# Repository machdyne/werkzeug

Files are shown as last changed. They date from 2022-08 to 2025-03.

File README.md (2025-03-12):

# Werkzeug USB Multi-Tool

Werkzeug is a USB multi-tool that can be used as a universal programmer, USB-UART bridge, USB-SPI bridge, USB-I2C bridge, USB host bridge, USB-PMOD bridge, programmable GPIO bit-bang device, logic analyzer, debugging tool and a lot more.

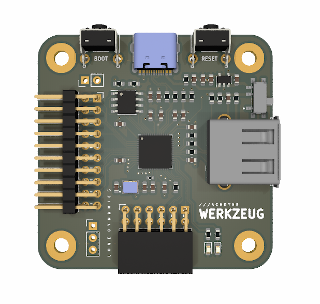
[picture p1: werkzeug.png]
Werkzeug USB Multi-Tool


This repo contains schematics, pinouts, a 3D-printable case, example firmware and documentation.

Find more information on the [Werkzeug product page](https://machdyne.com/product/werkzeug-multi-tool/).

## Firmware

The firmware can be updated by pressing the RESET button while holding down the BOOT button and then dragging and dropping a new UF2 file to the device filesystem.

### Firmware Resources

| Firmware | Description |
| --- | --- |
| test\_gpio | Test for GPIO and ADC |
| test\_usb\_host | Test for USB host port |
| micropython | [Micropython](https://micropython.org/) |
| [atio](https://github.com/machdyne/atio) | AT command set for controlling GPIO over USB CDC |
| [dev\_musli](https://github.com/machdyne/musli/tree/main/firmware/dev_musli) | Firmware for using Werkzeug with [ldprog](https://github.com/machdyne/ldprog) |
| [pico-dirtyJtag](https://github.com/machdyne/pico-dirtyJtag) | JTAG firmware |

Note: Our fork of dirtyJtag uses different GPIOs for JTAG than the original repo.

Note: The dirtyJtag\_alt.uf2 firmware is intended for a straight-through cable with 2x3 female headers where one wire has been removed. This cable can be plugged into the GPIO header (see pinout below).

### Building Firmware

To build the example firmware you will need to install the [Raspberry Pi Pico SDK](https://github.com/raspberrypi/pico-sdk).

Set the `PICO_SDK_PATH` environment variable to your SDK path.

```
$ git clone https://github.com/machdyne/werkzeug
$ cd werkzeug/firmware/test_gpio
$ mkdir build
$ cd build
$ cmake ..
$ make
```

This will create a UF2 file that can be programmed to the device using the method described above.

After the firmware is loaded you can see the output on the USB-C port:

```
minicom -D /dev/ttyACM0 -b 115200
```

## Pico Examples

```
$ git clone https://github.com/raspberrypi/pico-examples
$ cd pico-examples
$ mkdir build
$ cd build
$ cmake -DPICO_BOARD=machdyne_werkzeug ..
```

## Micropython

After the Micropython firmware is installed, you can access the REPL via the
USB-C port:

```
minicom -D /dev/ttyACM0 -b 115200
```

And then:

```
>>> help()
>>> help(machine.Pin.board) # list werkzeug pins
>>> green = machine.Pin('LED_GREEN', machine.Pin.OUT, value=1)
>>> red = machine.Pin('LED_RED', machine.Pin.OUT, value=1)
>>> green.value(0) # werkzeug LEDs are active low
```

You can use [ampy](https://learn.adafruit.com/micropython-basics-load-files-and-run-code/install-ampy) to upload scripts to the filesystem.

## USB Host Power

There is a switch near the USB Type-A female port that determines whether or not the port VBUS is connected to 5V.

Warning: Do not use a male-to-male cable with this port to connect Werkzeug to a computer when VBUS is connected.

## Resources

  * [RP2040 Datasheet (PDF)](https://datasheets.raspberrypi.com/rp2040/rp2040-datasheet.pdf)
  * [Getting started with Raspberry Pi Pico (PDF)](https://datasheets.raspberrypi.com/pico/getting-started-with-pico.pdf)
  * [Raspberry Pi Pico Examples](https://github.com/raspberrypi/pico-examples)
  * [TinyUSB Examples](https://github.com/hathach/tinyusb/tree/master/examples)

## Pinouts

### IO Header

```
1  2  3  4  5  6  7  8  9  10
11 12 13 14 15 16 17 18 19 20
```

| Pin | RP2040 Signal | dirtyJtag | dirtyJtag\_alt |
| --- | --- | --- | --- |
| 1 | GPIO0 | TCK |
| 2 | GPIO1 | TDI |
| 3 | GPIO2 | TDO |
| 4 | GPIO3 | TMS |
| 5 | GPIO4 |
| 6 | GPIO5 |
| 7 | GPIO6 | | TCK |
| 8 | GPIO7 | | TDO |
| 9 | GND |
| 10 | 3V3 |
| 11 | GPIO8 |
| 12 | GPIO9 |
| 13 | GPIO10 |
| 14 | GPIO11 |
| 15 | GPIO26/ADC0 |
| 16 | GPIO27/ADC1 |
| 17 | GPIO28/ADC2 | | TDI |
| 18 | GPIO29/ADC3 | | TMS |
| 19 | GND |
| 20 | 3V3 |

### PMOD

```
6  5  4  3  2  1
12 11 10 9  8  7
```

| Pin | Signal |
| --- | --- |
| 1 | GPIO19 |
| 2 | GPIO17 |
| 3 | GPIO15 |
| 4 | GPIO13 |
| 5 | GND |
| 6 | 3V3 |
| 7 | GPIO18 |
| 8 | GPIO16 |
| 9 | GPIO14 |
| 10 | GPIO12 |
| 11 | GND |
| 12 | 3V3 |

### Other Signals

| Signal | Description |
| --- | --- |
| GPIO20 | Green LED (active low) |
| GPIO21 | Red LED (active low) |
| GPIO22 | USB host VBUS status (controlled by switch) |
| GPIO23 | USB host D- |
| GPIO24 | USB host D+ |
| GPIO25 | USB host D+ pull-up |

## Board Revisions

| Revision | Notes |
| --- | ----- |
| V2 | Initial production version |
| V3 | Adds side boot/reset buttons and unpopulated SWD header |
| V3A | Has silkscreen error on bottom side unpopulated external power header (5V and GND labels are swapped and blacked out) |
| V3C | Current production version; fixes silkscreen error; increases flash to 4MB |

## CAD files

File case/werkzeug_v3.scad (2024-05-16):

/*
 * Werkzeug Case [for V3 boards]
 * Copyright (c) 2023 Lone Dynamics Corporation. All rights reserved.
 *
 * required hardware:
 *  - 4 x M3 x 16mm countersunk bolts
 *  - 4 x M3 nuts
 *
 */

$fn = 100;

werkzeug_text = true;

board_width = 50;
board_thickness = 1.5;
board_length = 50;
board_spacing = 2;

//ldp_board();

translate([0,0,15])
	ldp_case_top();

//translate([0,0,-5])
//	ldp_case_bottom();

module ldp_board() {
	
	difference() {
		color([0,0.5,0])
			roundedcube(board_width,board_length,board_thickness,5);
		translate([5, 5, -1]) cylinder(d=3.2, h=10);
		translate([5, 45, -1]) cylinder(d=3.2, h=10);
		translate([45, 5, -1]) cylinder(d=3.2, h=10);
		translate([45, 45, -1]) cylinder(d=3.2, h=10);
	}	
	
}

module ldp_case_top() {

	union() {

		difference() {

			color([0.5,0.5,0.5])
				roundedcube(board_width,board_length,10,5);

			translate([10.5,8,-17.5])
				cube([board_width-17.5,board_length-15,25]);

			translate([2.5,9,-22])
				cube([20,32,25]);

			translate([2.5,9,-17.5])
				cube([20,24,25]);

			translate([30,5,-20.5])
				cube([10,20,25]);

			translate([26,9,-17.5])
				cube([20,32,25]);

			// GPIO
			translate([25-13.5,board_length-20,-2])
				cube([27,25,6+2]);
		
			// BOOT BUTTON
			translate([30,36.525-(7.6/2),-2]) cube([30,7.6,7+1.75]);

			// RESET BUTTON
			translate([30,13.525-(7.6/2),-2]) cube([30,7.6,7+1.75]);

			// USBC
			translate([30,25-(10.5/2),-2]) cube([30,10.5,3.5+1.75]);

			// USBA HOST
			translate([25-(14.5/2),-2,-2]) cube([14.5,30,7.5+2]);

			// USBA HOST switch
			translate([35.5-(6.8/2),-2,-2]) cube([9,30,1.6+2]);
		
			// PMODA
			translate([-2,25-(16/2),-2]) cube([25,16,5+2]);

			// bolt holes
			translate([5, 5, -21]) cylinder(d=3.5, h=40);
			translate([5, 45, -21]) cylinder(d=3.5, h=40);
			translate([45, 5, -20]) cylinder(d=3.5, h=40);
			translate([45, 45, -21]) cylinder(d=3.5, h=40);

			// flush mount bolt holes
			translate([5, 5, 9.5]) cylinder(d=6, h=4);
			translate([5, 45, 9.5]) cylinder(d=6, h=4);
			translate([45, 5, 9.5]) cylinder(d=6, h=4);
			translate([45, 45, 9.5]) cylinder(d=6, h=4);

			// werkzeug text
			if (werkzeug_text) {
				rotate(270)
					translate([-25,25-(3/2),9])
						linear_extrude(2)
							text("W E R K Z E U G", size=3, halign="center",
								font="Ubuntu:style=Bold");
			}

		}	
	
	}

}

module ldp_case_bottom() {
	
	difference() {
		color([0.5,0.5,0.5])
			roundedcube(board_width,board_length,4.4,5);
		
		translate([1,8.5,2])
			roundedcube(board_width-2,board_length-17,8,5);
				
		translate([9,1,2])
			roundedcube(board_width-18,board_length-2,8,5);

		// bolt holes
		translate([5, 5, -11]) cylinder(d=3.2, h=25);
		translate([5, 45, -11]) cylinder(d=3.2, h=25);
		translate([45, 5, -11]) cylinder(d=3.2, h=25);
		translate([45, 45, -11]) cylinder(d=3.2, h=25);

		// nut holes
		translate([5, 5, -1.5]) cylinder(d=7, h=4.5, $fn=6);
		translate([5, 45, -1.5]) cylinder(d=7, h=4.5, $fn=6);
		translate([45, 5, -1.5]) cylinder(d=7, h=4.5, $fn=6);
		translate([45, 45, -1.5]) cylinder(d=7, h=4.5, $fn=6);

	}	
}

// https://gist.github.com/tinkerology/ae257c5340a33ee2f149ff3ae97d9826
module roundedcube(xx, yy, height, radius)
{
    translate([0,0,height/2])
    hull()
    {
        translate([radius,radius,0])
        cylinder(height,radius,radius,true);

        translate([xx-radius,radius,0])
        cylinder(height,radius,radius,true);

        translate([xx-radius,yy-radius,0])
        cylinder(height,radius,radius,true);

        translate([radius,yy-radius,0])
        cylinder(height,radius,radius,true);
    }
}

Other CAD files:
case/werkzeug_v2.scad

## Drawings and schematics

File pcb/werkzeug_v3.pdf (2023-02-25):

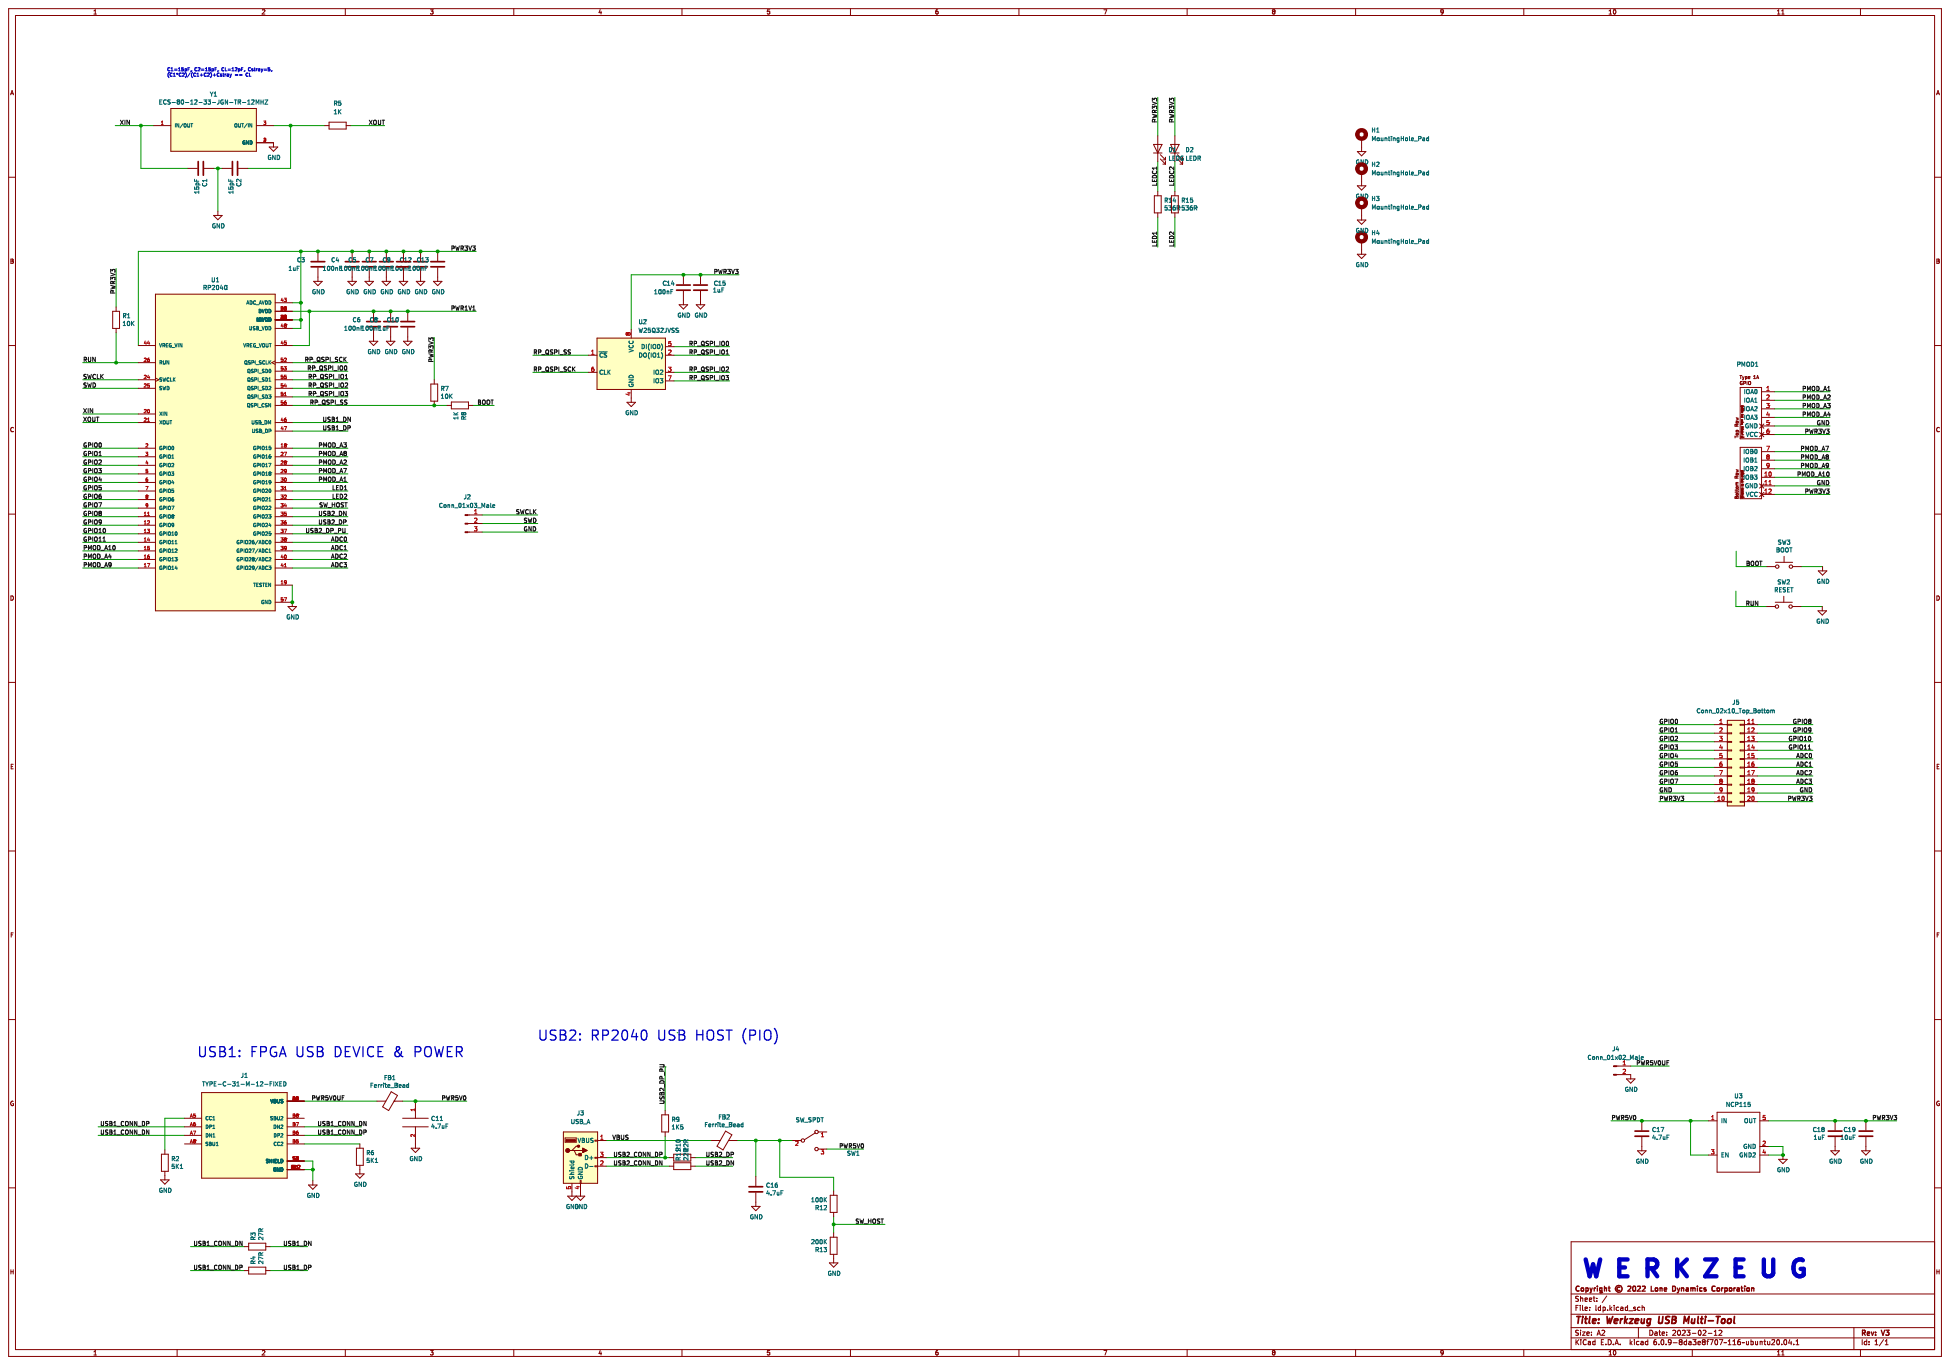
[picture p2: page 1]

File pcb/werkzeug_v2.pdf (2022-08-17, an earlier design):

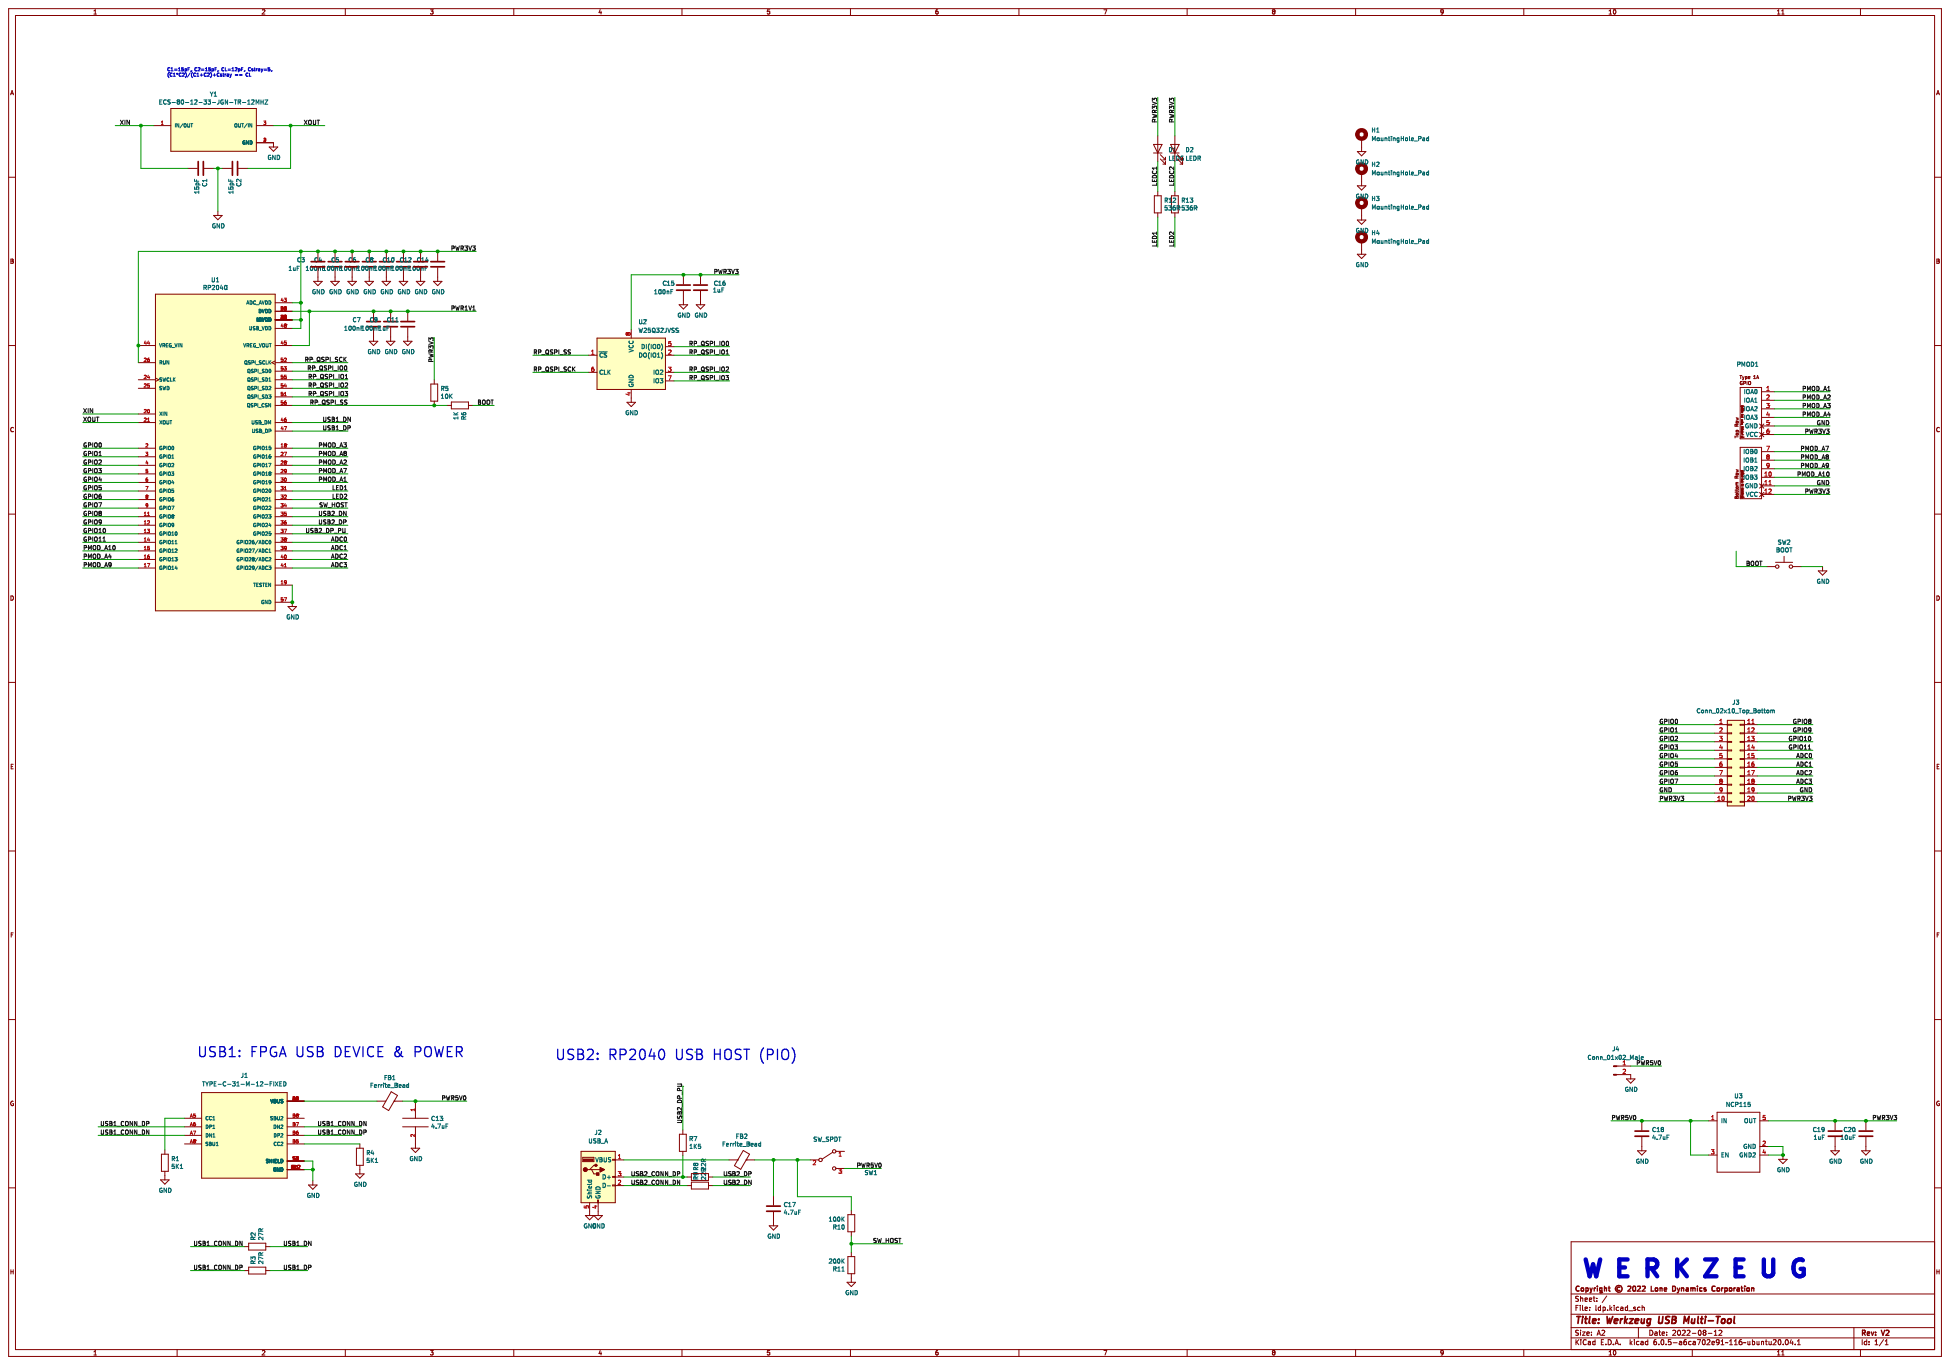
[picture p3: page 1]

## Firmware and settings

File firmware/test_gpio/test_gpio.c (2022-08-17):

/**
 * Copyright (c) 2020 Raspberry Pi (Trading) Ltd.
 * Copyright (c) 2022 Lone Dynamics Corporation <info@lonedynamics.com>
 *
 * SPDX-License-Identifier: BSD-3-Clause
 *
 * Werkzeug GPIO/ADC Test Firmware
 *
 */

#include <stdio.h>
#include <strings.h>

// Pico
#include "pico/stdlib.h"
#include "hardware/watchdog.h"
#include "hardware/adc.h"
#include "pico/stdlib.h"
#include "pico/binary_info.h"

void init_gpio_test(void) {

	gpio_init(0);	// GPIO0
		gpio_set_dir(0, true);
	gpio_init(1);	// GPIO1
		gpio_set_dir(1, true);
	gpio_init(2);	// GPIO2
		gpio_set_dir(2, true);
	gpio_init(3);	// GPIO3
		gpio_set_dir(3, true);
	gpio_init(4);	// GPIO4
		gpio_set_dir(4, true);
	gpio_init(5);	// GPIO5
		gpio_set_dir(5, true);
	gpio_init(6);	// GPIO6
		gpio_set_dir(6, true);
	gpio_init(7);	// GPIO7
		gpio_set_dir(7, true);
	gpio_init(8);	// GPIO8
		gpio_set_dir(8, true);
	gpio_init(9);	// GPIO9
		gpio_set_dir(9, true);
	gpio_init(10);	// GPIO10
		gpio_set_dir(10, true);
	gpio_init(11);	// GPIO11
		gpio_set_dir(11, true);
	gpio_init(12);	// PMOD_A10
		gpio_set_dir(12, true);
	gpio_init(13);	// PMOD_A4
		gpio_set_dir(13, true);
	gpio_init(14);	// PMOD_A9
		gpio_set_dir(14, true);
	gpio_init(15);	// PMOD_A3
		gpio_set_dir(15, true);
	gpio_init(16);	// PMOD_A8
		gpio_set_dir(16, true);
	gpio_init(17);	// PMOD_A2
		gpio_set_dir(17, true);
	gpio_init(18);	// PMOD_A7
		gpio_set_dir(18, true);
	gpio_init(19);	// PMOD_A1
		gpio_set_dir(19, true);
	gpio_init(20);	// LED1
		gpio_set_dir(20, true);
	gpio_init(21);	// LED2
		gpio_set_dir(21, true);
	gpio_init(22);	// SW_HOST
		gpio_set_pulls(22, false, false);

	adc_init();
	adc_gpio_init(26);
		gpio_set_pulls(26, false, false);
	adc_gpio_init(27);
		gpio_set_pulls(27, false, false);
	adc_gpio_init(28);
		gpio_set_pulls(28, false, false);
	adc_gpio_init(29);
		gpio_set_pulls(29, false, false);

}

int main(void) {

	stdio_init_all();

	printf("gpio_test initializing ...\n");
	init_gpio_test();

	int gpioctr = 0;
	int pmodctr = 0;
	int led = 0;

	const float conversion_factor = 3.3f / (1 << 12);

	while (1) {

		for (int i = 0; i < 12; i++) gpio_put(0+i, 0);
		for (int i = 0; i < 8; i++) gpio_put(12+i, 0);

		gpio_put(0+gpioctr, 1);
		gpio_put(12+pmodctr, 1);

		if (++gpioctr == 12) gpioctr = 0;
		if (++pmodctr == 8) pmodctr = 0;

		if (led) {
			gpio_put(20, 0);
			gpio_put(21, 1);
			led = 0;
		} else {
			gpio_put(20, 1);
			gpio_put(21, 0);
			led = 1;
		}

		adc_select_input(0);
		float adc0 = adc_read() * conversion_factor;
		adc_select_input(1);
		float adc1 = adc_read() * conversion_factor;
		adc_select_input(2);
		float adc2 = adc_read() * conversion_factor;
		adc_select_input(3);
		float adc3 = adc_read() * conversion_factor;

		printf("sw_host: %i adc0: %f adc1: %f adc3: %f adc4: %f\n",
			gpio_get(22), adc0, adc1, adc2, adc3);

		sleep_ms(500);

	}

	return 0;

}

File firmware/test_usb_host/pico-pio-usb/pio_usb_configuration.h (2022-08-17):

#pragma once

typedef enum {
  PIO_USB_PINOUT_DPDM = 0,  // DM = DP +1
  PIO_USB_PINOUT_DMDP,      // DM = DP -1
} PIO_USB_PINOUT;

typedef struct {
  uint8_t pin_dp;
  PIO_USB_PINOUT pinout;
  uint8_t pio_tx_num;
  uint8_t sm_tx;
  uint8_t tx_ch;
  uint8_t pio_rx_num;
  uint8_t sm_rx;
  uint8_t sm_eop;
  void* alarm_pool;
  int8_t debug_pin_rx;
  int8_t debug_pin_eop;
} pio_usb_configuration_t;

#ifndef PIO_USB_DP_PIN_DEFAULT
#define PIO_USB_DP_PIN_DEFAULT 24
#endif

#ifndef PIO_USB_PINOUT_DEFAULT
#define PIO_USB_PINOUT_DEFAULT PIO_USB_PINOUT_DMDP
#endif

//#define PIO_USB_DM_PIN_DEFAULT (PIO_USB_DP_PIN_DEFAULT - 1)

#define PIO_USB_TX_DEFAULT 0
#define PIO_SM_USB_TX_DEFAULT 0
#define PIO_USB_DMA_TX_DEFAULT 0

#define PIO_USB_RX_DEFAULT 1
#define PIO_SM_USB_RX_DEFAULT 0
#define PIO_SM_USB_EOP_DEFAULT 1

#define PIO_USB_DEBUG_PIN_NONE (-1)

#define PIO_USB_DEFAULT_CONFIG                                             \
  {                                                                        \
    PIO_USB_DP_PIN_DEFAULT, PIO_USB_PINOUT_DEFAULT, PIO_USB_TX_DEFAULT,    \
        PIO_SM_USB_TX_DEFAULT, PIO_USB_DMA_TX_DEFAULT, PIO_USB_RX_DEFAULT, \
        PIO_SM_USB_RX_DEFAULT, PIO_SM_USB_EOP_DEFAULT, NULL,               \
        PIO_USB_DEBUG_PIN_NONE, PIO_USB_DEBUG_PIN_NONE                     \
  }

#define PIO_USB_EP_POOL_CNT 32
#define PIO_USB_DEV_EP_CNT 16
#define PIO_USB_DEVICE_CNT 4
#define PIO_USB_HUB_PORT_CNT 8
#define PIO_USB_ROOT_PORT_CNT 2

#define PIO_USB_EP_SIZE 64

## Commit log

2022-08-19 increase gpio height
    [werkzeug.scad]
2023-02-08 update case; increase boot hole size
    [werkzeug.scad]
2023-02-08 fix corner radius
    [werkzeug.scad]
2023-02-08 add hardware notes
    [werkzeug.scad]
2023-02-08 remove led vent
    [werkzeug.scad]
2023-02-25 add v3
    [werkzeug_v2.scad, werkzeug_v3.scad]
2024-05-16 update case for werkzeugkopf
    [werkzeug_v3.scad]
2024-11-15 add custom cable info
